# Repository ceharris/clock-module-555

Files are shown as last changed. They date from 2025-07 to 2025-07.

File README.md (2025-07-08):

clock-module-555
================

This repository contains KiCad sources for a clock module based on a
design by Ben Eater as presented on his YouTube channel. Ben's version
of this module uses a mechanical toggle switch to select the free-running
or single-step mode. This version uses a more easily sourced push button
to toggle a flip-flop to select the mode. Both the mode select button
and the clock pulse button are debounced using 555 timers in monostable
configuration.

In free-running mode, the clock frequency can be varied using the 
on-board potentiometer, ranging from about 1 Hz to about 3 KHz.

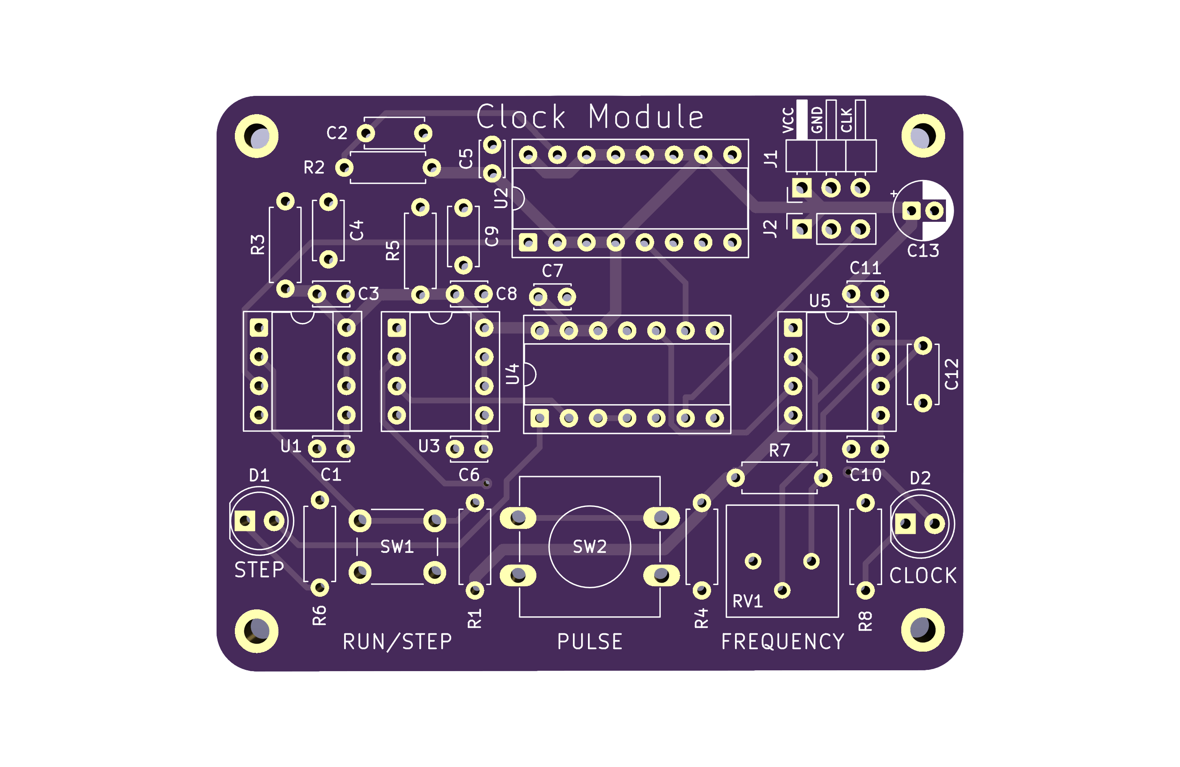
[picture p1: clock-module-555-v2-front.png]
Clock Module PCB Front

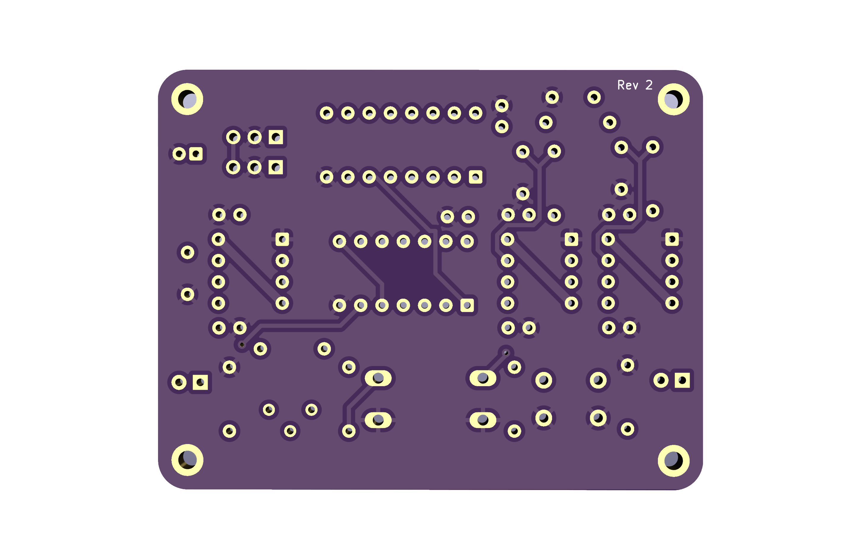
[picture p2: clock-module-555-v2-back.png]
Clock Module PCB Back

Clock Module Photo

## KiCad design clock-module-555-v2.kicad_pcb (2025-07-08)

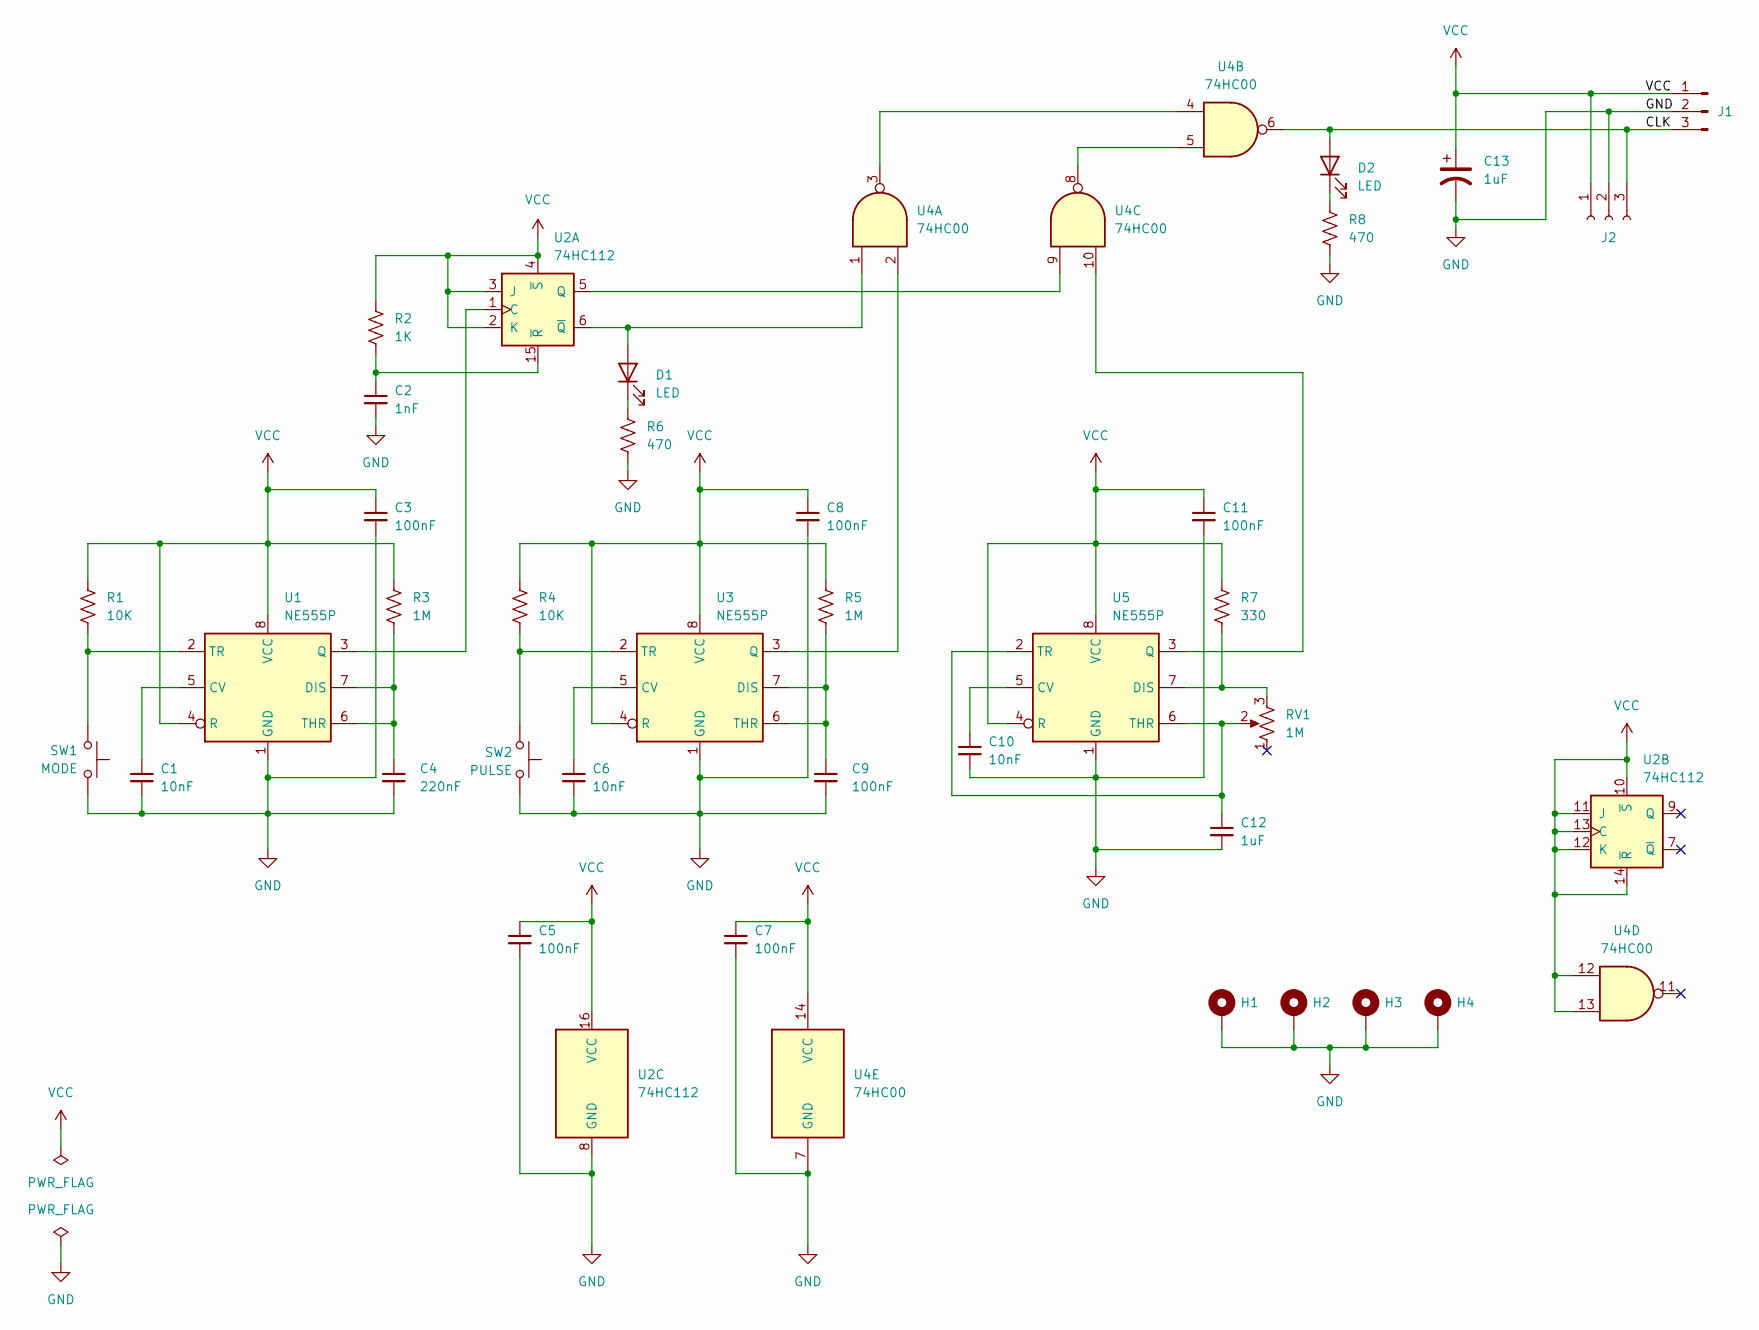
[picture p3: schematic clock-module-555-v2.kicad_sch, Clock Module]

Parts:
C1, C6, C10: 10nF; C_Disc_D3.0mm_W2.0mm_P2.50mm
C2: 1nF; C_Disc_D5.0mm_W2.5mm_P5.00mm
C3, C5, C7, C8, C11: 100nF; C_Disc_D3.0mm_W2.0mm_P2.50mm
C4: 220nF; C_Disc_D5.0mm_W2.5mm_P5.00mm
C9: 100nF; C_Disc_D5.0mm_W2.5mm_P5.00mm
C12: 1uF; C_Disc_D5.0mm_W2.5mm_P5.00mm
C13: 1uF; CP_Radial_D5.0mm_P2.00mm
D1, D2: LED; LED_D5.0mm
H1, H2, H3, H4: MountingHole_Pad; MountingHole_2.2mm_M2_DIN965_Pad
J1: Conn_01x03_Pin; PinHeader_1x03_P2.54mm_Horizontal
J2: Conn_01x03_Socket; PinSocket_1x03_P2.54mm_Vertical
R1, R4: 10K; R_Axial_DIN0207_L6.3mm_D2.5mm_P7.62mm_Horizontal
R2: 1K; R_Axial_DIN0207_L6.3mm_D2.5mm_P7.62mm_Horizontal
R3, R5: 1M; R_Axial_DIN0207_L6.3mm_D2.5mm_P7.62mm_Horizontal
R6, R8: 470; R_Axial_DIN0207_L6.3mm_D2.5mm_P7.62mm_Horizontal
R7: 330; R_Axial_DIN0207_L6.3mm_D2.5mm_P7.62mm_Horizontal
RV1: 1M; Potentiometer_Bourns_3386P_Vertical
SW1: MODE; SW_PUSH_6mm
SW2: PULSE; SW_PUSH-12mm
U1, U3, U5: NE555P; DIP-8_W7.62mm_Socket
U2: 74HC112; DIP-16_W7.62mm_Socket
U4: 74HC00; DIP-14_W7.62mm_Socket

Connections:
/CLK: D2.2 (A), J1.3, J2.3, U4.6
GND: C1.2, C2.2, C3.2, C4.2, C5.2, C6.2, C7.2, C8.2, C9.2, C10.2, C11.2, C12.2, C13.2, H1.1, H2.1, H3.1, H4.1, J1.2, J2.2, R6.2, R8.2, SW1.2, SW2.2, U1.1 (GND), U2.8 (GND), U3.1 (GND), U4.7 (GND), U5.1 (GND)
unnamed: D1.2 (A), U2.6 (~Q), U4.1
unnamed: D1.1 (K), R6.1
unnamed: D2.1 (K), R8.1
unnamed: C1.1, U1.5 (CV)
unnamed: C4.1, R3.2, U1.6 (THR), U1.7 (DIS)
unnamed: U1.3 (Q), U2.1 (C)
unnamed: R1.2, SW1.1, U1.2 (TR)
unnamed: U2.5 (Q), U4.9
unnamed: C2.1, R2.2, U2.15 (~R)
unnamed: C6.1, U3.5 (CV)
unnamed: C9.1, R5.2, U3.6 (THR), U3.7 (DIS)
unnamed: U3.3 (Q), U4.2
unnamed: R4.2, SW2.1, U3.2 (TR)
unnamed: U4.3, U4.4
unnamed: U4.5, U4.8
unnamed: C10.1, U5.5 (CV)
unnamed: R7.2, RV1.3, U5.7 (DIS)
unnamed: U4.10, U5.3 (Q)
unnamed: C12.1, RV1.2, U5.2 (TR), U5.6 (THR)
VCC: C3.1, C5.1, C7.1, C8.1, C11.1, C13.1, J1.1, J2.1, R1.1, R2.1, R3.1, R4.1, R5.1, R7.1, U1.4 (R), U1.8 (VCC), U2.2 (K), U2.3 (J), U2.4 (~S), U2.10 (~S), U2.11 (J), U2.12 (K), U2.13 (C), U2.14 (~R), U2.16 (VCC), U3.4 (R), U3.8 (VCC), U4.12, U4.13, U4.14 (VCC), U5.4 (R), U5.8 (VCC)

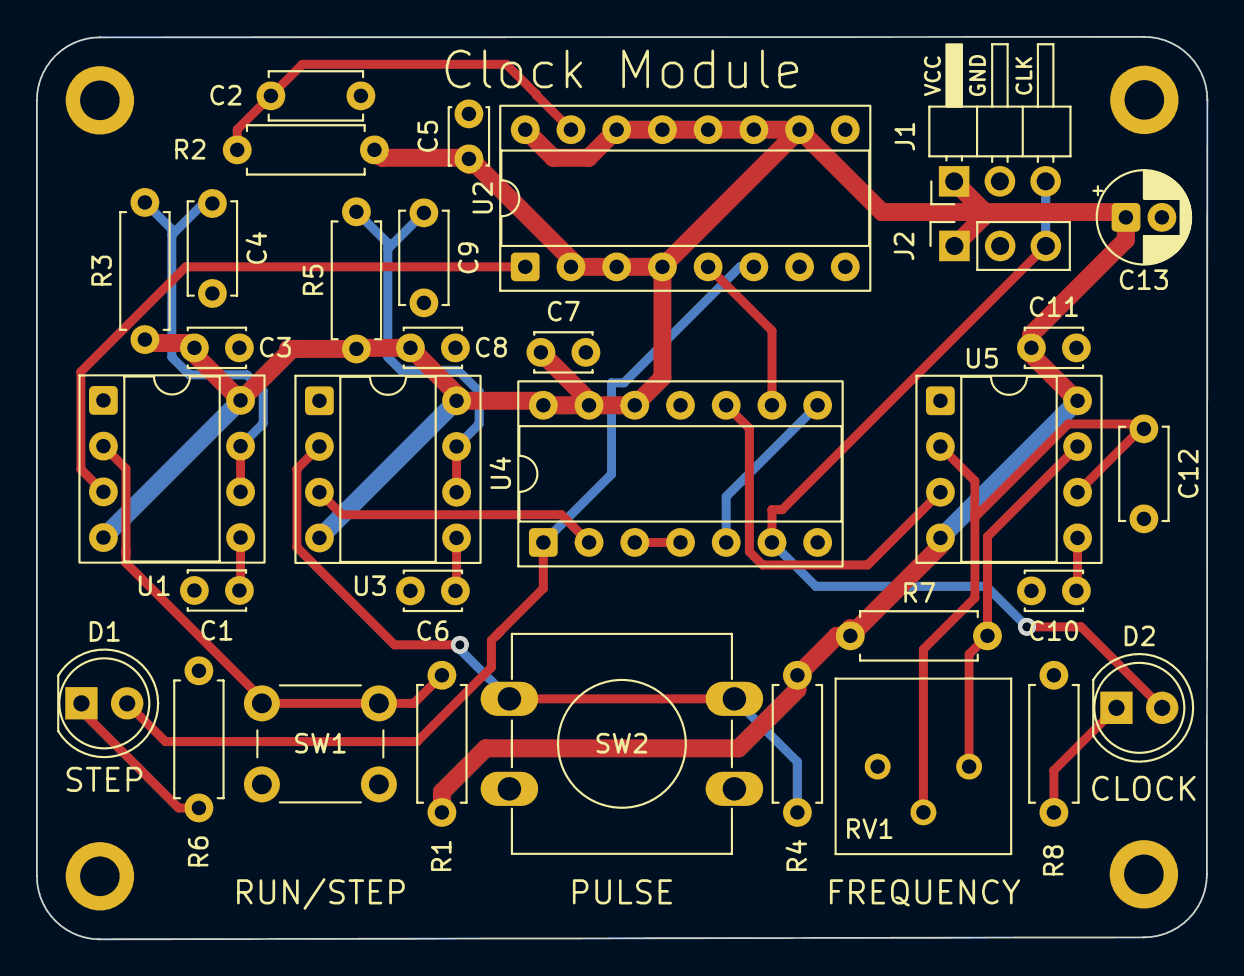
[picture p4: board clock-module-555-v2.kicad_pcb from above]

Board: 2 copper layers, 65.0 x 50.1 mm, 37 parts (0 on the bottom side), 22 nets.

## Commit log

2025-07-08 revisions after first build
    [clock-module-555-v2.kicad_pcb, clock-module-555-v2.kicad_sch]
2025-07-08 marked as rev 2
    [clock-module-555-v2.kicad_pcb, clock-module-555-v2.kicad_sch]
2025-07-08 gerber setup
    [clock-module-555-v2.kicad_pcb]
2025-07-08 added PNGs for board to README
2025-07-08 revised PCB back image
